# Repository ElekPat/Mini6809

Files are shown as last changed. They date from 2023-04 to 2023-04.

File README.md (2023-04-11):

This is my Kicad version of http://www.christle.us/index.php?P=1

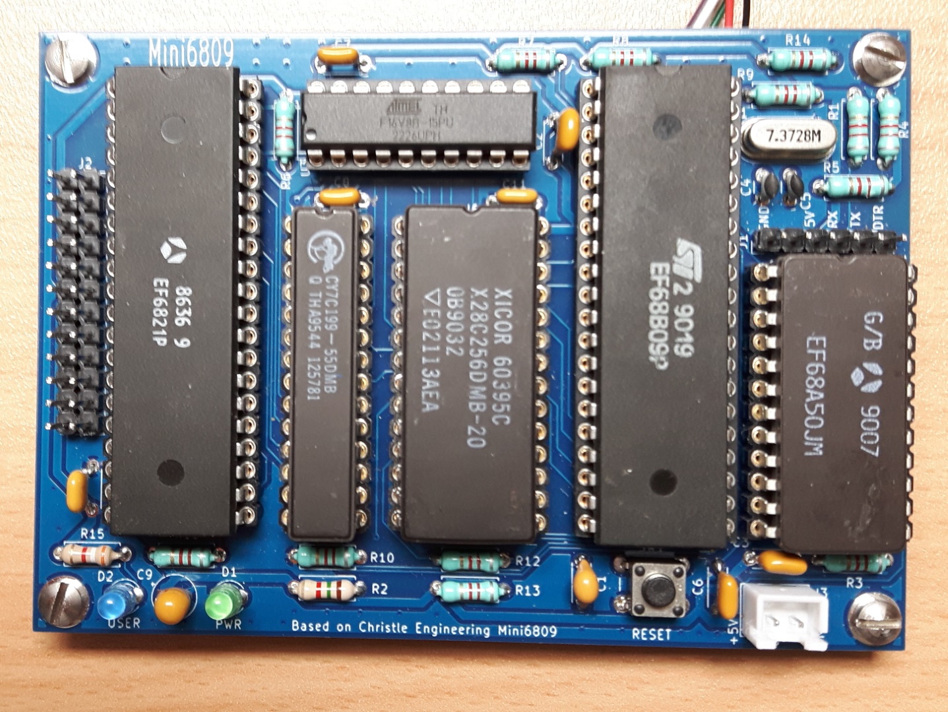
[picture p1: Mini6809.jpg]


I replaced the SIP resistor network with traditional through hole resistors.

I added a blue user led connected to PA1 and I added a reset button.

I removed the 5V regulator and provided a standard 2 pin JST connector for external +5V supply (not normally required as the Serial socket connected to a FTDI like USB to serial adapter will provide the necessary +5V).

For assembling source files, I use http://john.ccac.rwth-aachen.de:8000/as/ (Macro Assembler compatible with multiple target CPUs, see my other projects)

Use the following 2 command lines to generate a S19 file:
 - asw.exe -cpu 6809 -L source.asm
 - p2hex.exe source.p +5 -k -F Moto

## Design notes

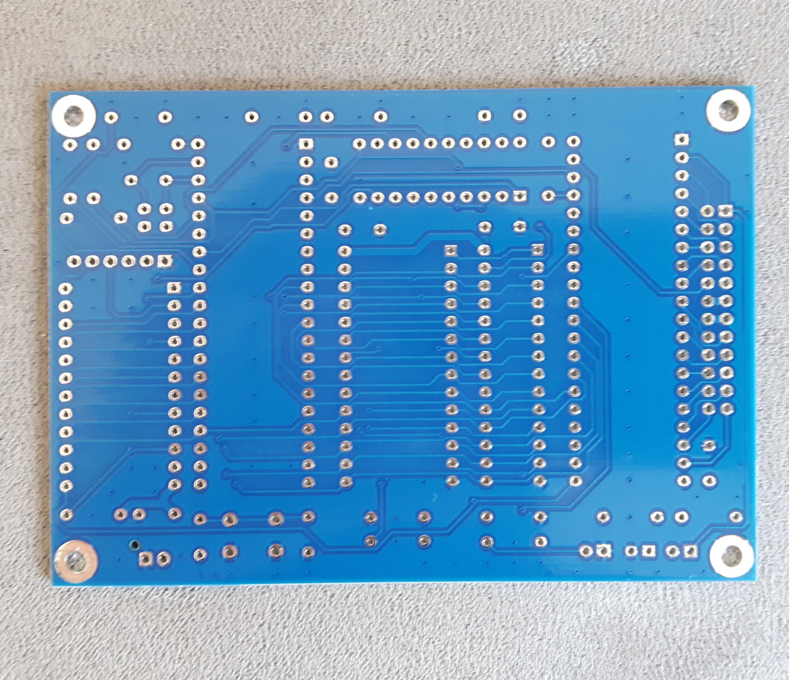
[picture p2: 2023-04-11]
Mini6809_Bot.jpg

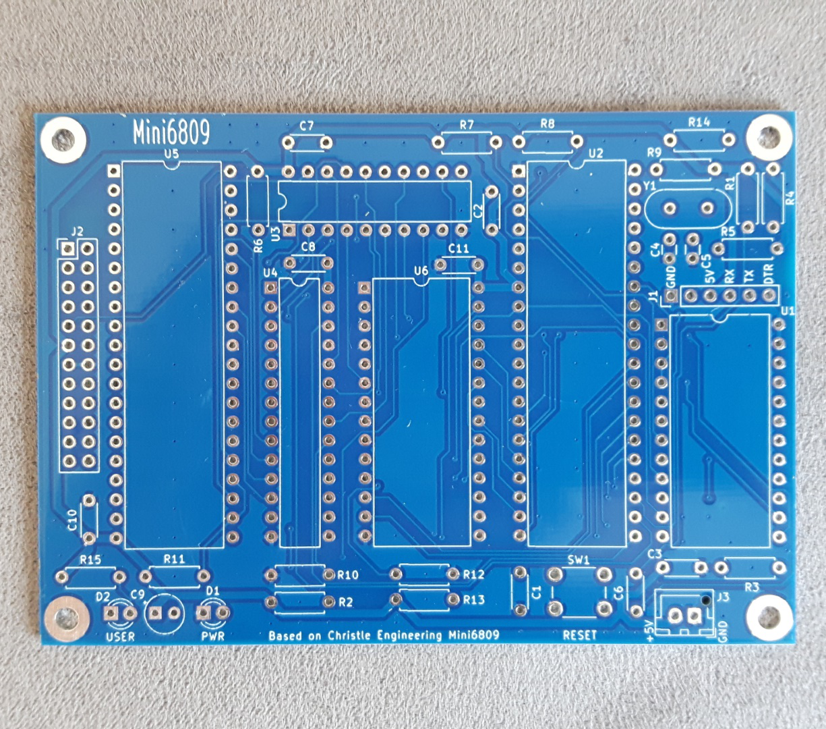
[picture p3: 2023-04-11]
Mini6809_Top.jpg

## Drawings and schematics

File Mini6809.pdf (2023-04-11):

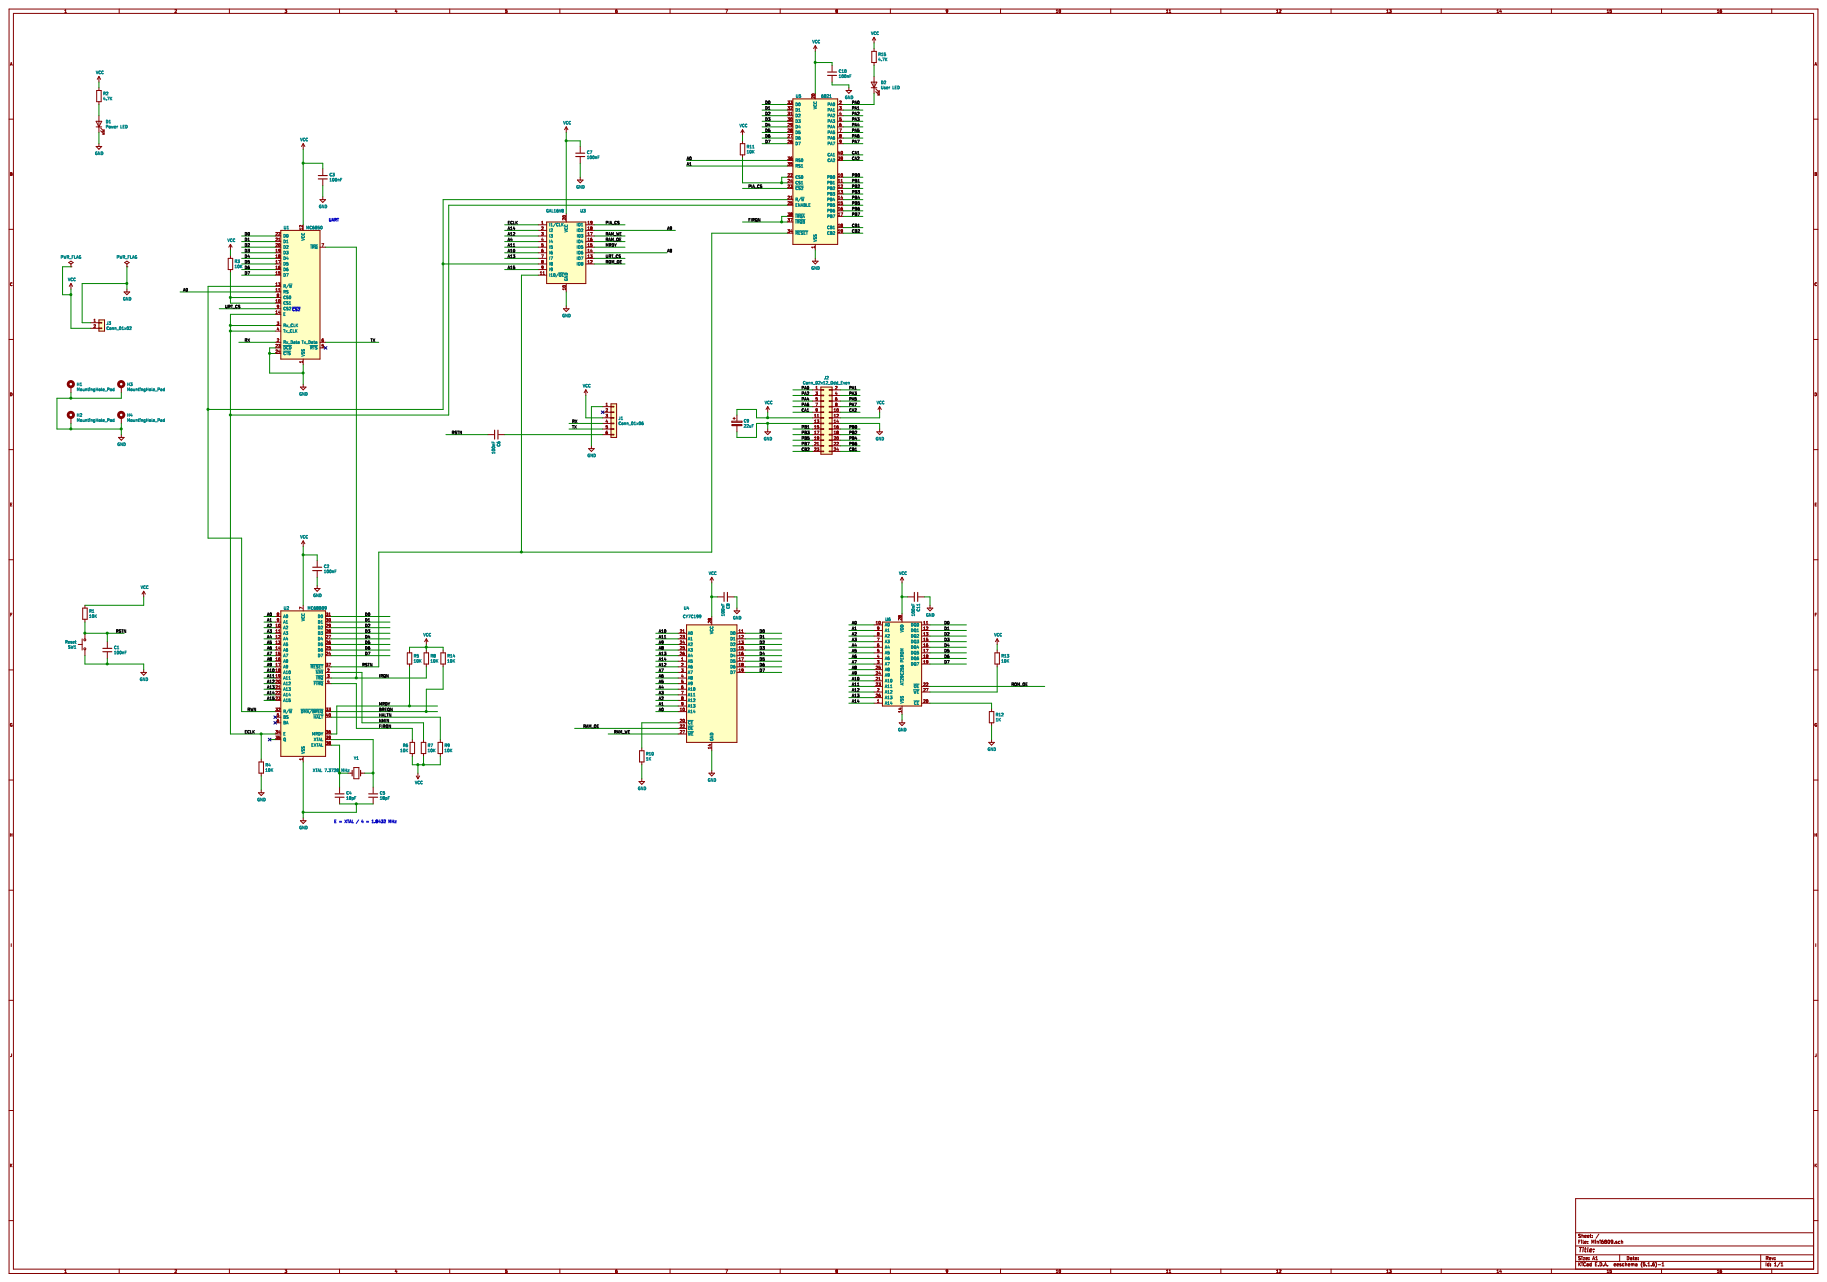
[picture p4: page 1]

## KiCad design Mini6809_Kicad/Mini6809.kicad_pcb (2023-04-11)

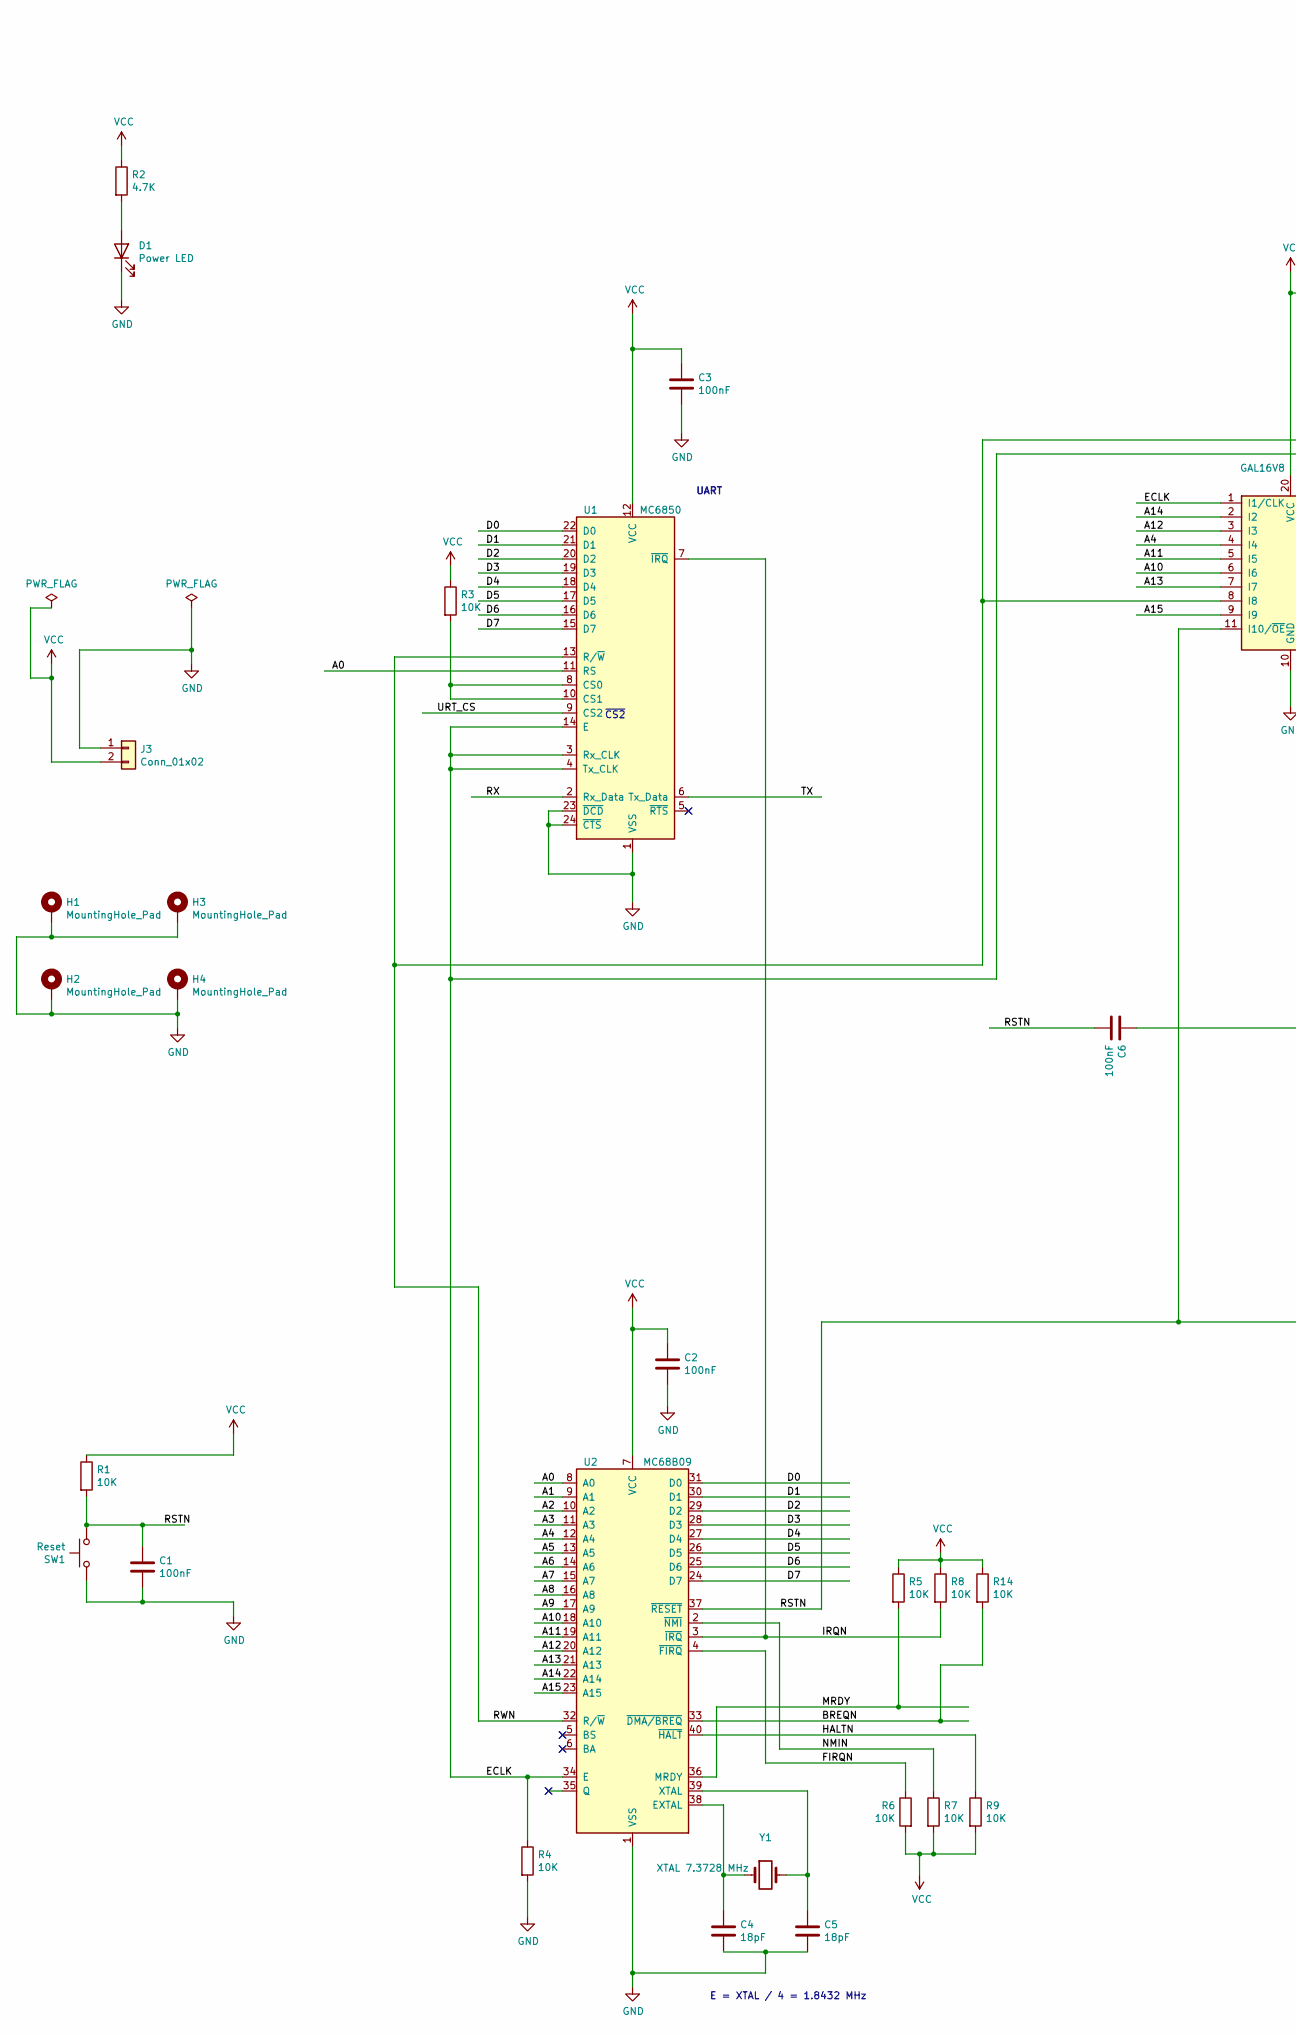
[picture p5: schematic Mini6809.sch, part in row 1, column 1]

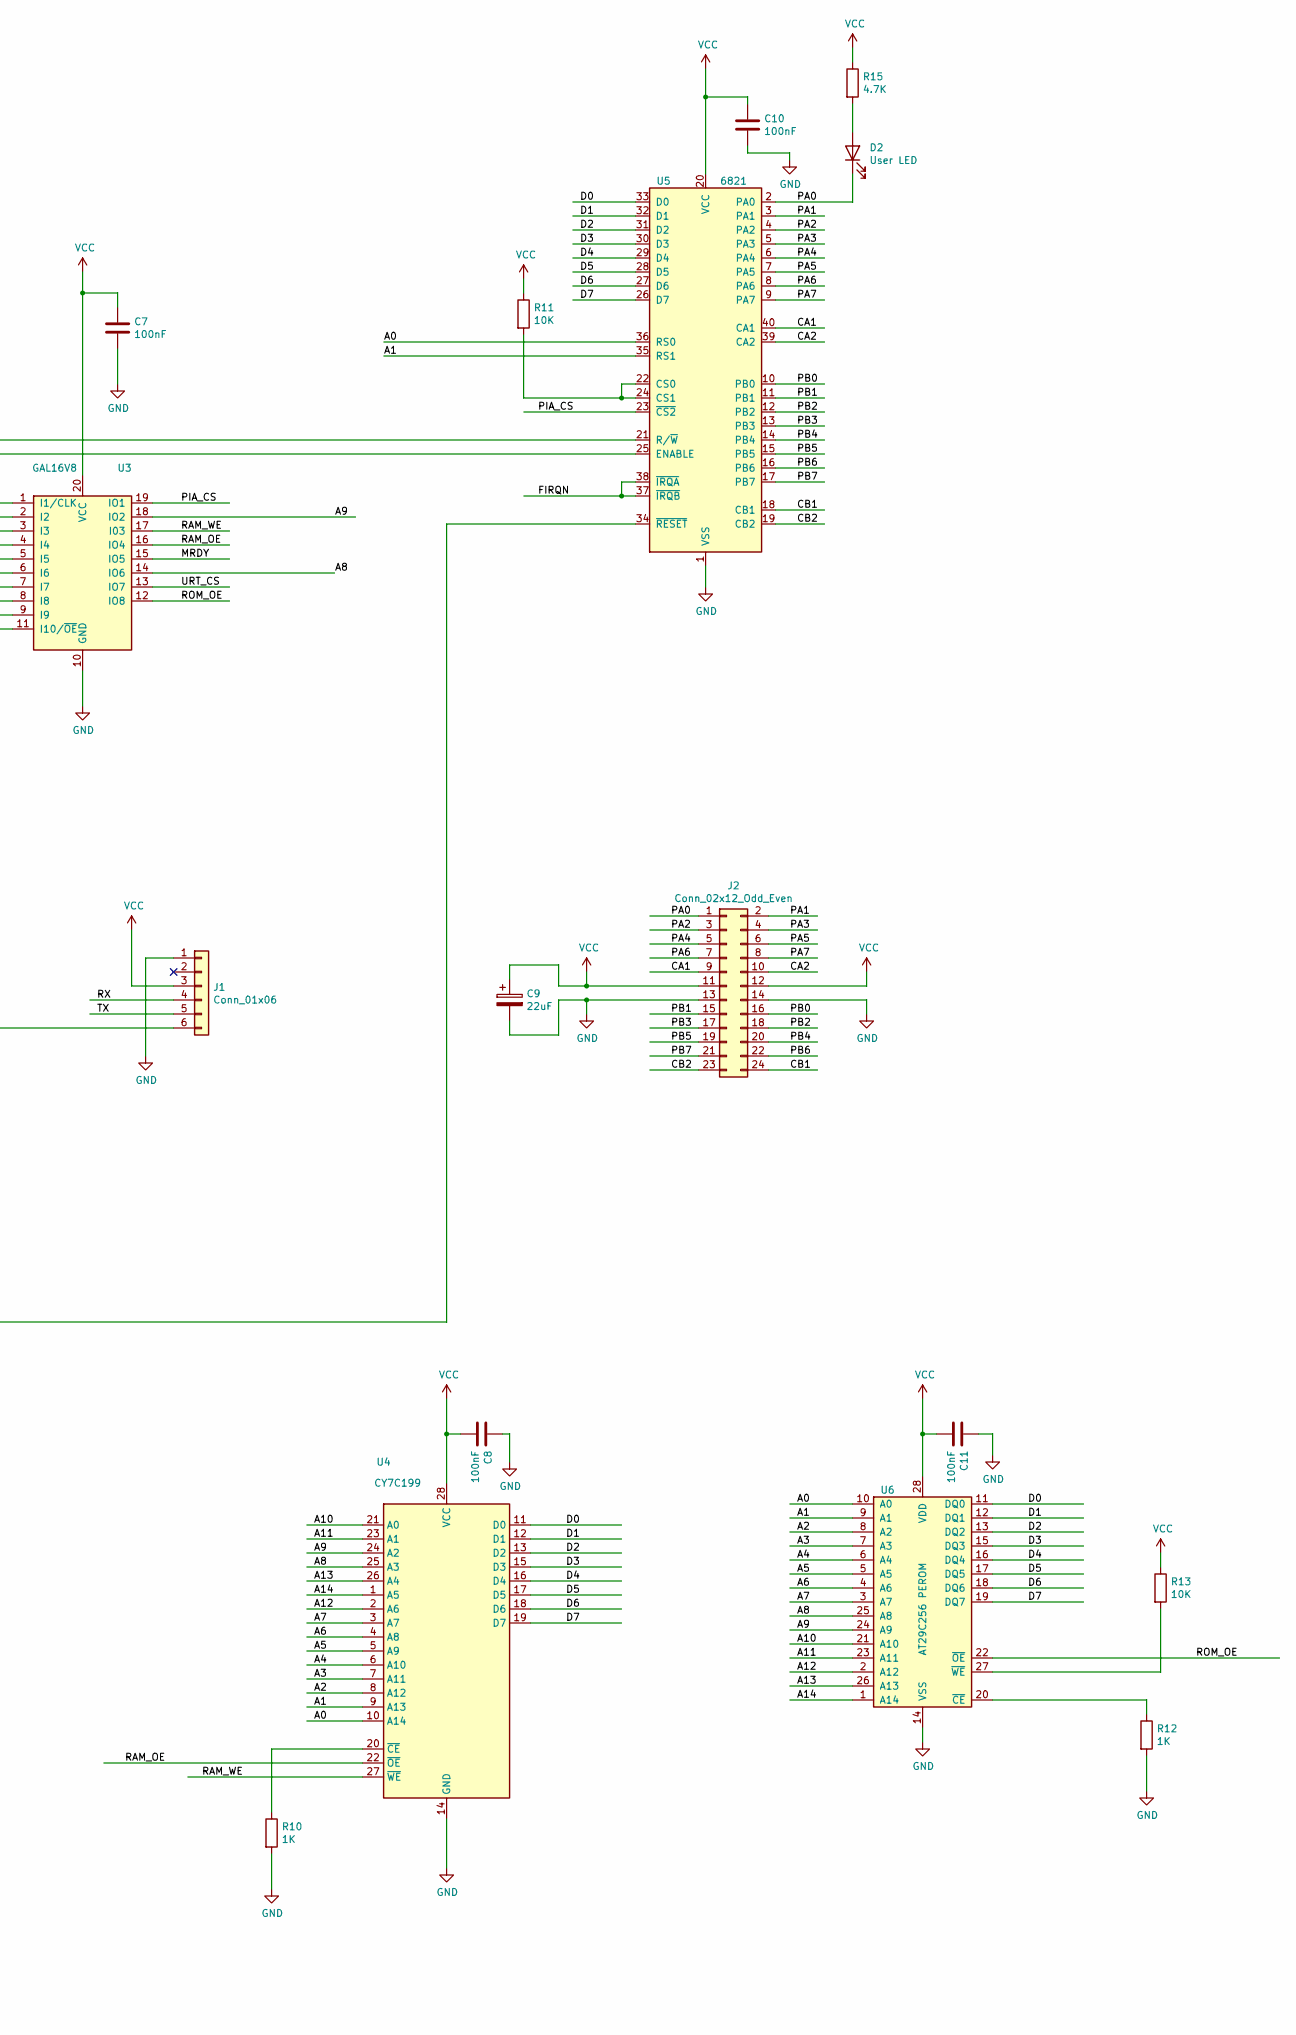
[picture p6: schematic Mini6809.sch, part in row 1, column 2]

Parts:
C1, C2, C3, C6, C7, C8, C10, C11: 100nF; C_Disc_D4.3mm_W1.9mm_P5.00mm
C4, C5: 18pF; C_Disc_D3.0mm_W1.6mm_P2.50mm
C9: 22uF; CP_Radial_Tantal_D5.0mm_P2.50mm
D1: Power LED; LED_D3.0mm
D2: User LED; LED_D3.0mm
H1, H2, H3, H4: MountingHole_Pad; MountingHole_3mm_Pad
J1: Conn_01x06; PinHeader_1x06_P2.54mm_Vertical
J2: Conn_02x12_Odd_Even; PinHeader_2x12_P2.54mm_Vertical
J3: Conn_01x02; JST_XH_B2B-XH-AM_1x02_P2.50mm_Vertical
R1, R3, R4, R5, R6, R7, R8, R9, R11, R13, R14: 10K; R_Axial_DIN0207_L6.3mm_D2.5mm_P7.62mm_Horizontal
R2, R15: 4.7K; R_Axial_DIN0207_L6.3mm_D2.5mm_P7.62mm_Horizontal
R10, R12: 1K; R_Axial_DIN0207_L6.3mm_D2.5mm_P7.62mm_Horizontal
SW1: Reset; SW_PUSH_6mm
U1: MC6850; DIP-24_W15.24mm
U2: MC68B09; DIP-40_W15.24mm
U3: GAL16V8; DIP-20_W7.62mm
U4: CY7C199; DIP-28_W7.62mm
U5: 6821; DIP-40_W15.24mm
U6: AT29C256 PEROM; DIP-28_W15.24mm
Y1: XTAL 7.3728 MHz; Crystal_HC49-U_Vertical

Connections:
/A0: U1.11 (RS), U2.8 (A0), U4.10 (A14), U5.36 (RS0), U6.10 (A0)
/A1: U2.9 (A1), U4.9 (A13), U5.35 (RS1), U6.9 (A1)
/A2: U2.10 (A2), U4.8 (A12), U6.8 (A2)
/A3: U2.11 (A3), U4.7 (A11), U6.7 (A3)
/A4: U2.12 (A4), U3.4 (I4), U4.6 (A10), U6.6 (A4)
/A5: U2.13 (A5), U4.5 (A9), U6.5 (A5)
/A6: U2.14 (A6), U4.4 (A8), U6.4 (A6)
/A7: U2.15 (A7), U4.3 (A7), U6.3 (A7)
/A8: U2.16 (A8), U3.14 (IO6), U4.25 (A3), U6.25 (A8)
/A9: U2.17 (A9), U3.18 (IO2), U4.24 (A2), U6.24 (A9)
/A10: U2.18 (A10), U3.6 (I6), U4.21 (A0), U6.21 (A10)
/A11: U2.19 (A11), U3.5 (I5), U4.23 (A1), U6.23 (A11)
/A12: U2.20 (A12), U3.3 (I3), U4.2 (A6), U6.2 (A12)
/A13: U2.21 (A13), U3.7 (I7), U4.26 (A4), U6.26 (A13)
/A14: U2.22 (A14), U3.2 (I2), U4.1 (A5), U6.1 (A14)
/A15: U2.23 (A15), U3.9 (I9)
/BREQN: R14.2, U2.33 (~DMA/BREQ)
/CA1: J2.9, U5.40 (CA1)
/CA2: J2.10, U5.39 (CA2)
/CB1: J2.24, U5.18 (CB1)
/CB2: J2.23, U5.19 (CB2)
/D0: U1.22 (D0), U2.31 (D0), U4.11 (D0), U5.33 (D0), U6.11 (DQ0)
/D1: U1.21 (D1), U2.30 (D1), U4.12 (D1), U5.32 (D1), U6.12 (DQ1)
/D2: U1.20 (D2), U2.29 (D2), U4.13 (D2), U5.31 (D2), U6.13 (DQ2)
/D3: U1.19 (D3), U2.28 (D3), U4.15 (D3), U5.30 (D3), U6.15 (DQ3)
/D4: U1.18 (D4), U2.27 (D4), U4.16 (D4), U5.29 (D4), U6.16 (DQ4)
/D5: U1.17 (D5), U2.26 (D5), U4.17 (D5), U5.28 (D5), U6.17 (DQ5)
/D6: U1.16 (D6), U2.25 (D6), U4.18 (D6), U5.27 (D6), U6.18 (DQ6)
/D7: U1.15 (D7), U2.24 (D7), U4.19 (D7), U5.26 (D7), U6.19 (DQ7)
/ECLK: R4.1, U1.3 (Rx_CLK), U1.4 (Tx_CLK), U1.14 (E), U2.34 (E), U3.1 (I1/CLK), U5.25 (ENABLE)
/FIRQN: R6.1, U2.4 (~FIRQ), U5.37 (~IRQB), U5.38 (~IRQA)
/HALTN: R9.1, U2.40 (~HALT)
/IRQN: R8.2, U1.7 (~IRQ), U2.3 (~IRQ)
/MRDY: R5.2, U2.36 (MRDY), U3.15 (IO5)
/NMIN: R7.1, U2.2 (~NMI)
/PA0: D2.1 (K), J2.1, U5.2 (PA0)
/PA1: J2.2, U5.3 (PA1)
/PA2: J2.3, U5.4 (PA2)
/PA3: J2.4, U5.5 (PA3)
/PA4: J2.5, U5.6 (PA4)
/PA5: J2.6, U5.7 (PA5)
/PA6: J2.7, U5.8 (PA6)
/PA7: J2.8, U5.9 (PA7)
/PB0: J2.16, U5.10 (PB0)
/PB1: J2.15, U5.11 (PB1)
/PB2: J2.18, U5.12 (PB2)
/PB3: J2.17, U5.13 (PB3)
/PB4: J2.20, U5.14 (PB4)
/PB5: J2.19, U5.15 (PB5)
/PB6: J2.22, U5.16 (PB6)
/PB7: J2.21, U5.17 (PB7)
/PIA_CS: U3.19 (IO1), U5.23 (~CS2)
/RAM_OE: U3.16 (IO4), U4.22 (~OE~)
/RAM_WE: U3.17 (I03), U4.27 (~WE~)
/ROM_OE: U3.12 (IO8), U6.22 (~OE~)
/RSTN: C1.1, C6.2, R1.2, SW1.1, U2.37 (~RESET), U3.11 (I10/~OE~), U5.34 (~RESET)
/RWN: U1.13 (R/~W), U2.32 (R/~W), U3.8 (I8), U5.21 (R/~W)
/RX: J1.4, U1.2 (Rx_Data)
/TX: J1.5, U1.6 (Tx_Data)
/URT_CS: U1.9 (CS2), U3.13 (IO7)
GND: C1.2, C2.2, C3.2, C4.2, C5.2, C7.2, C8.1, C9.2, C10.2, C11.1, D1.1 (K), H1.1, H2.1, H3.1, H4.1, J1.1, J2.13, J2.14, J3.1, R4.2, R10.2, R12.2, SW1.2, U1.1 (VSS), U1.23 (~DCD), U1.24 (~CTS), U2.1 (VSS), U3.10 (GND), U4.14 (GND), U5.1 (VSS), U6.14 (VSS)
unnamed: C4.1, U2.38 (EXTAL), Y1.1
unnamed: C5.1, U2.39 (XTAL), Y1.2
unnamed: C6.1, J1.6
unnamed: D1.2 (A), R2.2
unnamed: D2.2 (A), R15.2
unnamed: R3.2, U1.8 (CS0), U1.10 (CS1)
unnamed: R10.1, U4.20 (~CE~)
unnamed: R11.2, U5.22 (CS0), U5.24 (CS1)
unnamed: R12.1, U6.20 (~CE~)
unnamed: R13.2, U6.27 (~WE~)
VCC: C2.1, C3.1, C7.1, C8.2, C9.1, C10.1, C11.2, J1.3, J2.11, J2.12, J3.2, R1.1, R2.1, R3.1, R5.1, R6.2, R7.2, R8.1, R9.2, R11.1, R13.1, R14.1, R15.1, U1.12 (VCC), U2.7 (VCC), U3.20 (VCC), U4.28 (VCC), U5.20 (VCC), U6.28 (VDD)

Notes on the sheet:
E = XTAL / 4 = 1.8432 MHz
~CS2
UART

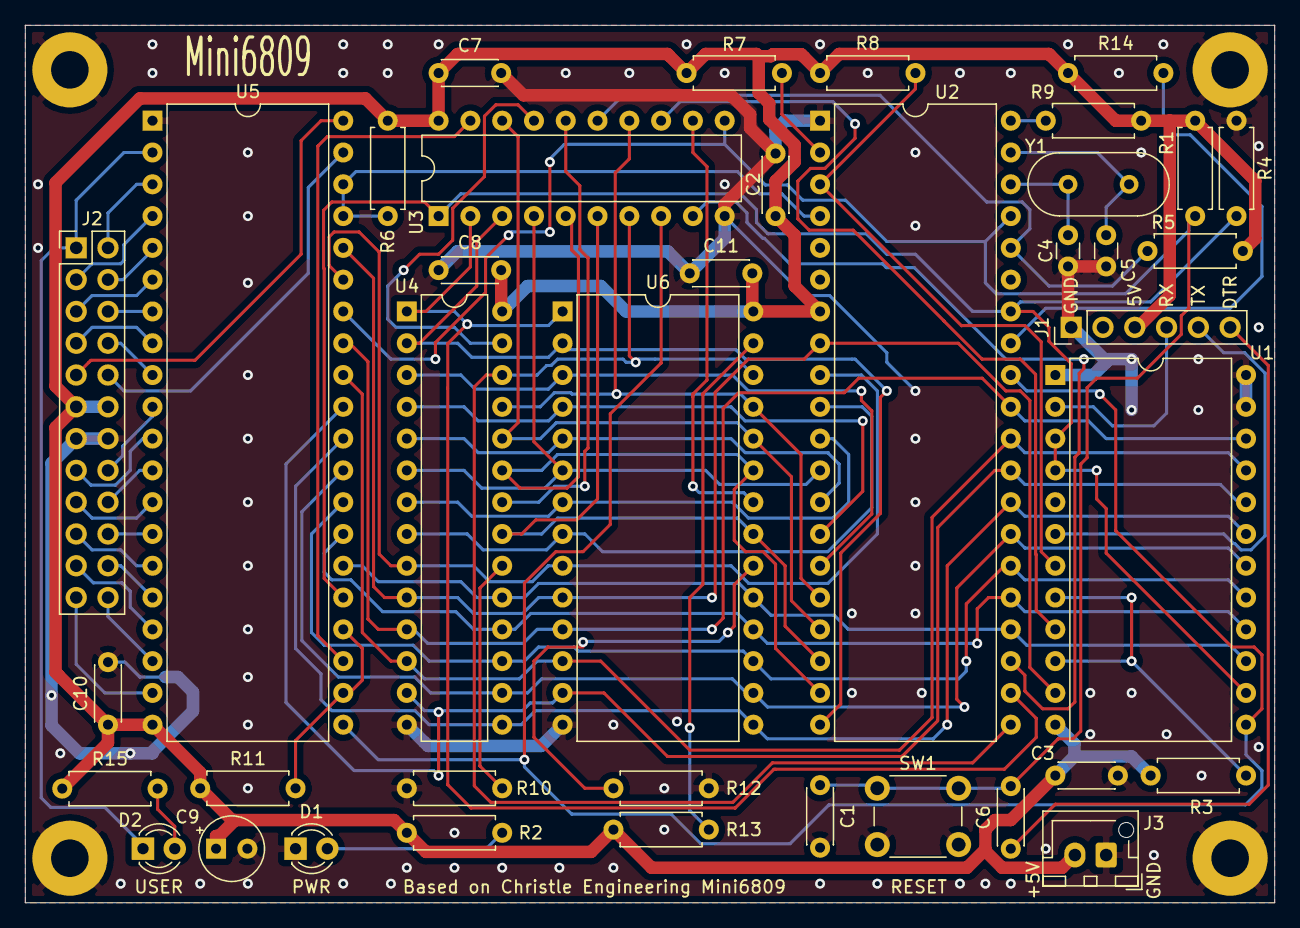
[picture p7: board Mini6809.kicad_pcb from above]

Board: 2 copper layers, 99.8 x 70.1 mm, 43 parts (0 on the bottom side), 72 nets.

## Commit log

2023-04-11 Add Kicad files
    [Mini6809.kicad_pcb, Mini6809.sch]
2023-04-11 Add Schematics in PDF format
